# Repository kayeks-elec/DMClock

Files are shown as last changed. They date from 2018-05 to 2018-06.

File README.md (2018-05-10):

# DMCLOCK

## Overview

A Desktop clock project using AVR8 microcontroller and 32-by-16 dots LED matrix
module.

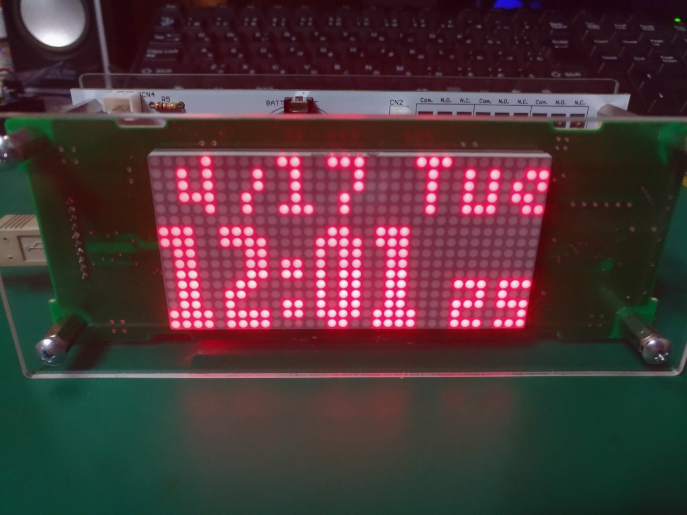
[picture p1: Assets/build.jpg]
Photo of a build


## Features
  - Display ambient temperature
  - Clock backup during power off
  - Four-level display brightness select, including automatic leveling with
    on-board ambient light sensor
  - Three-channel relay output triggerable by specified clock time and
    days-of-week.
  - Clock correction from GPS receiver
  - Serial message output (see below)

## Specifications
  - **Power**  
      - 5V DC from USB B connector, 250 mA typ., 800 mA max. including LED
        module
      - 3V DC from CR2032 cell, 10 nA typ. for clock backup
  - **Dimensions**  
    145 mm × 54 mm × 46 mm, viewing area 82 mm × 41 mm
  - **Devices**  
      - ATMEGA328P, clocked at 20 MHz
      - DS1307+ real-time clock
  - **Inputs**  
      - Two push switches
      - Ambient light sensor
      - Temperature sensor
      - GPS receiver module (optional)
  - **Outputs**  
      - Three relay channels with two throws each; max. load 2A 30V DC, 1A 125V
        AC
      - Serial message output: 5V level, 8N1 at 9600 baud
  - **Clock accuracy**  
    Less than 1 second of relative error from GPS clock source

## Targeting display device

The targeting LED matrix module in this project is Product Number of AD-501,
manufactured by *Alpha Device Co.* of Japan. It has a viewing area of
monochromatic 32-by-16 dots in matrix arrangement. Therefore, this project
would be portable to other devices which have similar viewing areas if you
replace the device-specific interfacing routines.

## Microcontroller

This project uses an ATMEGA328P microcontroller.

### Clock configuration

The clock is 20 MHz from crystal oscillator (ceramic resonator also works but not recommended).

### Flashing firmware

Flash firmware `Firmware/DotMatrixClock2018.hex` directly by ISP, with fuses
Low byte **0xFF**, High byte **0xD9**, and Extended byte **0x07**.

## GPS clock correction

External GPS modules can be connected to GPS Receiver connector (CN3) for clock
time correction.

The pin assignment for GPS Receiver connector (CN3):

| Pin # | Description |
| --: | :-- |
| 1 | +5V power supply, fused by 100 mA polyfuse |
| 2 | GND |
| 3 | not connected |
| 4 | GPS receiver source |
| 5 | GPS receiver sink |

Note:  
The data line through pins 4 and 5 constitutes a current loop driver, and
its driving current is 5 mA, which is similar to the conventional MIDI
interfaces.

Any GPS module which meets requirements below woule be available for this
project:
  - **Serial format**  
    8N1 at 9,600 baud
  - **Messages**  
    NMEA 0183 messages contain `$GPGGA` and `$GPZDA` sentences

## Serial message output

Messages are transmitted from Serial Output connector (CN4). The output level
is 5 V. Serial format is 8N1 at 9,600 baud.

### Message strings

#### Local clock date
```text
D([0-9][0-9])-([01][0-9])-([0-3][0-9])\r\n
  where \1: last two digits of years
        \2: months
        \3: days
```

#### Local clock time
```text
T([0-9][0-9]):([01][0-9]):([0-3][0-9])\r\n
  where \1: hours
        \2: minutes
        \3: seconds
```

#### Ambient temperature
```text
A([+-])([01][0-9][0-9].[0-9][0-9])\r\n
  if temperature is available
  where \1: sign of temperature
        \2: absolute value of temperature
A xxx.xx\r\n
  if temperature is unavailable
```

## License

Modified BSD License  
See `LICENSE` for details.

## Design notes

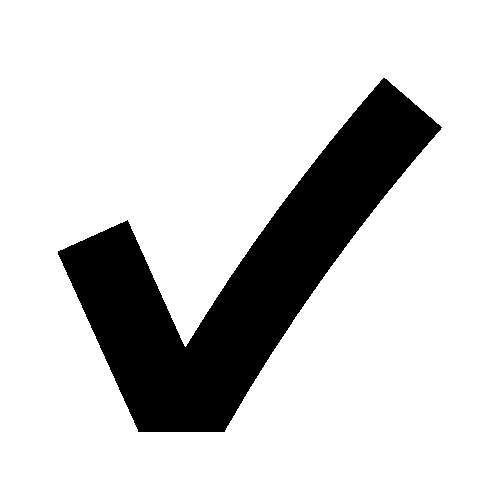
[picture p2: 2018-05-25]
Hardware/Mainboard/BallotSign.bmp

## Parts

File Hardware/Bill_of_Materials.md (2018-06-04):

# Bill of Materials

## Mainboard

| Nr. | Location | Category | Details | Qty. |
|----:|:---|:---|:---|-----:|
| 1 | R4 | carbon film resistor | 220 ohm | 1 |
| 2 | R1, R3, R5, R7, R9, R11 | carbon film resistor | 1K ohm | 6 |
| 3 | R12 | carbon film resistor | 2.2K ohm (depending on characteristics of RP) | 1 |
| 4 | R6, R8, R10 | carbon film resistor | 4.7K ohm | 3 |
| 5 | R2, R13, R14 | carbon film resistor | 10K ohm | 3 |
| 6 | RP | photocell | 10K - 20K ohm @ 10 lux, 1M ohm @ dark | 1 |
| 7 | F1 | resettable fuse | ≥10 V, 1.1 A | 1 |
| 8 | F2 | resettable fuse | ≥10 V, 0.1 A | 1 |
| 9 | C7, C8 | ceramic capacitor | 10 pF (depending on characteristics of Y2) | 2 |
| 10 | C4, C5 | ceramic capacitor | 22 pF (depending on characteristics of Y1) | 2 |
| 11 | C2, C3, C6, C9 | multilayer ceramic capacitor | 100 nF | 4 |
| 12 | C1 | electrolytic capacitor | ≥10 V, 220 uF | 1 |
| 13 | Y1 | crystal oscillator | 20.000 MHz | 1 |
| 14 | Y2 | crystal oscillator | 32.768 KHz | 1 |
| 15 | D1, D2, D3, D4 | rectifier diode | *1N4148* | 4 |
| 16 | LD1 | light emitting diode | *red* | 1 |
| 17 | LD2 | light emitting diode | *yellow green* | 1 |
| 18 | LD3, LD4, LD5 | light emitting diode | *yellow* | 3 |
| 19 | Q1, Q2, Q4, Q5, Q6 | NPN transistor | *2N3904* | 5 |
| 20 | Q3 | optoisolator | *PC817* | 1 |
| 21 | U1 | AVR8 microcontroller | ATMEGA328P-PU, `Firmware/DotMatrixClock2018.hex` programmed, fuses H=0xFF L=0xD9 E=0x07 | 1 |
| 22 | U2 | real-time clock | DS1307+ | 1 |
| 23 | U3 | digital temperature sensor | ADT7410TRZ | 1 |
| 24 | CN1 | USB B connector | | 1 |
| 25 | CN2 | JST PH connector | B10B-PH-K-S | 1 |
| 26 | CN3 | DIN connector | 5 poles | 1 |
| 27 | CN4 | pin header | 6 poles, single row, right angle | 1 |
| 28 | CN5, CN6, CN7 | solderless terminal block | 3 poles | 3 |
| 29 | CN8 | box header | 6 poles | 1 |
| 30 | BATT | CR2032 coin cell holder | | 1 |
| 31 | SW1, SW2 | push switch | | 2 |
| 32 | RY1, RY2, RY3 | magnetic relay | 5 V, double throw, *946H-1C-5D* | 3 |
| 33 | - | LED panel module | AD-501 from Alpha Device Co. | 1 |

## GPS Receiver

| Nr. | Location | Category | Details | Qty. |
|----:|:---|:---|:---|-----:|
| 1 | R1, R2 | carbon film resistor | 220 ohm | 2 |
| 2 | R3, R4 | carbon film resistor | 1K ohm | 2 |
| 3 | C1 | electrolytic capacitor | ≥10 V, 22 uF | 1 |
| 4 | U1 | GPS module | AE-GYSFDMAX from Akizuki Denshi | 2 |
| 5 | (U1) | pin header | 5 poles, single row | 1 |
| 6 | (U1) | pin socket | 5 poles, single row | 1 |
| 7 | (U1) | standoff | M3, 11mm, brass | 4 |
| 8 | (U1) | screw | M3, 5mm (+), steel | 8 |
| 9 | CN1 | DIN connector | 5 poles | 1 |
| 10 | CN2 | pin header | 6 poles, single row, right angle | 1 |
| 11 | CN3 | pin header | 2 poles, single row, right angle | 1 |

  - P/Ns described in italic are reference designs. You can replace them to
    compatible parts as your availability.

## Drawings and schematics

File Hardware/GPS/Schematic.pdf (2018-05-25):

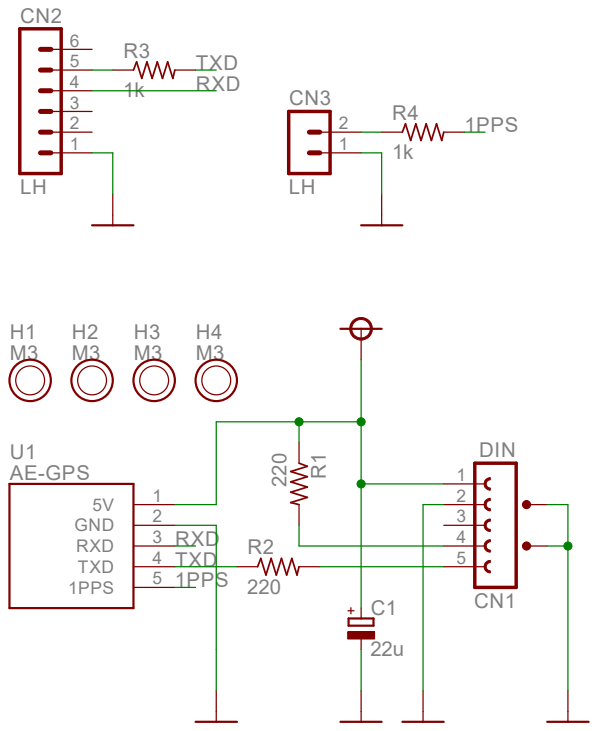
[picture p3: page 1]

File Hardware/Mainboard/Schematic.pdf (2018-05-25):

SCR.TERM. ¹k | 1N⁴¹⁴⁸ | 2.2k 10k | 10k | 10..20k@¹⁰lx/1M ⁰.1u | 0.1u 32.768k

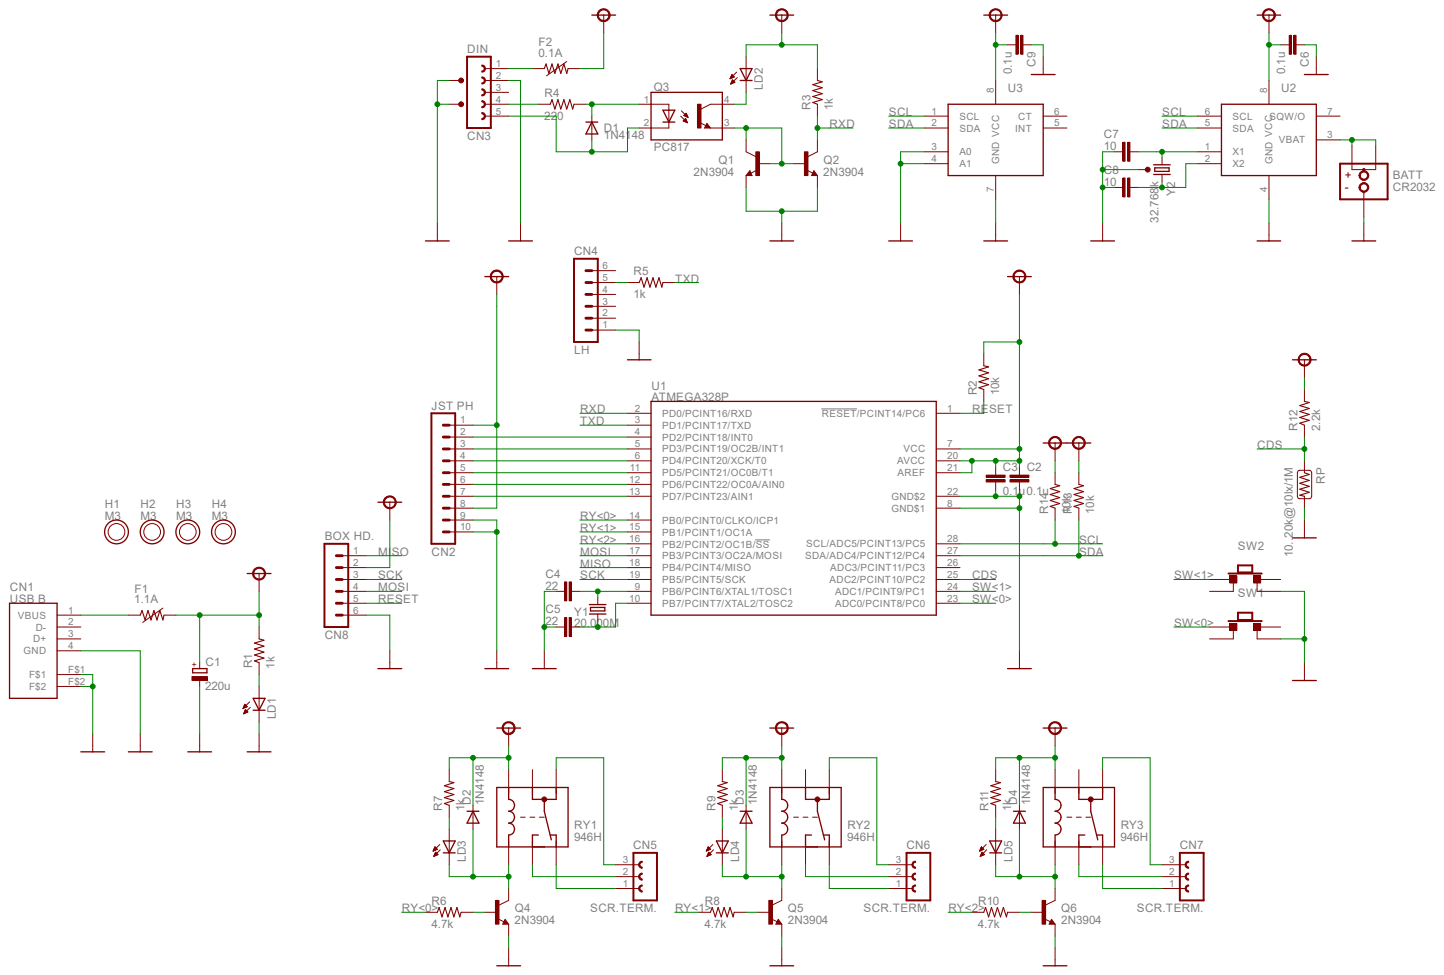
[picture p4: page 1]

PD5/PCINT21/OC0B/T1 11
PD6/PCINT22/OC0A/AIN0 12
PD7/PCINT23/AIN1 13

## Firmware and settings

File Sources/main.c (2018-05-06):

/*
 * DotMatrixClock2018/main.c
 *
 *  Author: kayekss
 *  Target: ATmega328P, 20.000 MHz crystal oscillator
 */

// System clock frequency in Hz
#define F_CPU  20000000ul

#include <stdint.h>
#include <stdbool.h>
#include <stdlib.h>
#include <string.h>
#include <avr/io.h>
#include <avr/interrupt.h>
#include "ctime.h"
#include "event.h"
#include "eeprom.h"
#include "eeprom_redundancy.h"
#include "keys.h"
#include "display.h"
#include "drawings.h"
#include "usart.h"
#include "nmea.h"
#include "twi.h"
#include "temp_adt7410.h"
#include "rtc_ds1307.h"
#include "adc.h"
#include "light_sensor.h"
#include "defs.h"

// -------- Global variables --------

// Elapsed time from startup in milliseconds
volatile uint32_t ticks = 0;

// Front frame buffer
extern uint32_t fb_front[16];

// ADC value of light sensor
uint16_t light_adc;

// USART receiver buffer
ringbuf_t rx;

// USART transmitter buffer
ringbuf_t tx;

// Working environment
struct {
    // Current status
    state_t status;
    // Current display brightness (0..4)
    uint8_t brightness;
    // Current internal time structure
    ctime_t ct;
    // Duplicated time structure used during modification
    ctime_t ct_mod;
    // Current week-of-day
    dow_t dow;
    // Week-of-day used during modification
    dow_t dow_mod;
    // GPS connection/tracking status
    struct {
        // Fix status
        gpstate_t status;
        // Satellites in use
        uint8_t sats_in_use;
    } gps;
    // T5 tasks
    struct {
        task5_t read_keys;
        task5_t read_temperature;
        task5_t draw_screen;
        task5_t get_light_level;
    } task5;
    // T6 tasks
    struct {
        task6_t save_ctime_to_rtc;
        task6_t check_relay_output;
        task6_t serial_output;
    } task6;
    // Key watchers
    key_t key0, key1;
    // Configuration structure and its duplication
    config_t config, config_mod;
    // Indexes used during relay setup in configuration mode
    struct {
        // Relay number currently indexing
        uint8_t r;
        // Event number currently indexing
        uint8_t e;
        // Day-of-week currently indexing
        dow_t dow;
    } relay_index;
    // Whether to save the configuration to EEPROM when it is done
    bool save_to_ee;
    // Buffer for EEPROM byte array
    uint8_t ee_blob[EEREDUN_CONFIG_STRIDE];
    // Temperature sensor status
    struct {
        // Result (0: no error, 1: error)
        bool result;
        // Temperature value
        temp_adt7410_t value;
        // Trigger flags
        uint8_t flags;
    } temperature;
    // Message buffer
    linebuf_t msg;
    // Ticks of last reception of '$' from USART
    uint32_t ticks_rx;
} env;

// Default clock time recalled on failure
ctime_t const ct_default = {
    1, 0, 1, 1, 0, 0, 0, 0
};

// EEPROM address map for configuration
eeredun_t const eer_config = {
    EEREDUN_CONFIG_REDUNDANCY,
    EEREDUN_CONFIG_STRIDE,
    { EEREDUN_CONFIG_BASE_TIMESTAMP, EEREDUN_CONFIG_BASE_ENTITY }
};

// -------- General functions --------

// Make an imprecise wait by busy-looping
void wait(uint32_t delay_ms) {
    uint32_t ticks_end_loop = ticks + delay_ms;

    while (ticks < ticks_end_loop);
}

// Get constrained value in range between specified
// ... minimum and maximum
inline uint8_t constrain(uint8_t n, uint8_t min, uint8_t max) {
    return n < min ? n : n > max ? max : n;
}

// Initialize T5 task
inline void t5_initialize(task5_t* t, uint32_t interval) {
    t->interval = interval;
    t->timestamp = 0;
}

// Check if the T5 task is triggered
inline bool t5_check_triggered(task5_t* t) {
    if (t->interval == 0) {
        return false;
    } else {
        return ticks >= t->timestamp + t->interval;
    }
}

// Set last-executed timestamp of the T5 task
inline void t5_set_timestamp(task5_t* t) {
    t->timestamp = ticks;
}

// Initialize T6 task
inline void t6_initialize(task6_t* t) {
    t->pending = false;
}

// Trigger T6 task
inline void t6_trigger(task6_t* t) {
    t->pending = true;
}

// Check if the T6 task is triggered
inline bool t6_check_triggered(task6_t* t) {
    return t->pending;
}

// Untrigger T6 task
inline void t6_done(task6_t* t) {
    t->pending = false;
}

// -------- Project-specific functions --------

// Setup EEPROM
void setup_eeprom() {
    EECR = (0 << EERIE) | (0 << EEMPE) | (0 << EEPE) | (0 << EERE);
    //     0b--XX0XXX  (-: reserved bits)
    //         |||||+-- EERE      EEPROM Read Enable
    //         ||||+--- EEPE      EEPROM Write Enable
    //         |||+---- EEMPE     EEPROM Master Write Enable 
    //         ||+----- EERIE     EEPROM Ready Interrupt Enable: no
    //         ++------ EEPM<1:0> EEPROM Programming Mode
}

// Setup I/O ports
void setup_io() {
    // == PORTB ==
    // PB7/XTAL2: crystal oscillator
    // PB6/XTAL1: crystal oscillator
    // PB5/SCK:   not in use, only for programming
    // PB4/MISO:  not in use, only for programming
    // PB3/MOSI:  not in use, only for programming
    // PB2:       Relay 2, normal-low output
    // PB1:       Relay 1, normal-low output
    // PB0:       Relay 0, normal-low output
    // == PORTC ==
    // PC6/RESET#: reset
    // PC5/SCL:    TWI serial bus clock
    // PC4/SDA:    TWI serial bus data
    // PC3:        not in use
    // PC2/ADC2:   Light sensor (photoresistor), analog input
    // PC1:        Push key 1, pulled-up input
    // PC0:        Push key 0, pulled-up input
    // == PORTD ==
    // PD7:     LED matrix module OE, output
    // PD6:     LED matrix module LAT, output
    // PD5:     LED matrix module CLK, output
    // PD4:     LED matrix module SIN3, output
    // PD3:     LED matrix module SIN2, output
    // PD2:     LED matrix module SIN1, output
    // PD1/TXD: USART transmitter, output
    // PD0/RXD: USART receiver, input
    PORTB = (0 << PORTB7) | (0 << PORTB6) | (0 << PORTB5) | (0 << PORTB4) |
        (0 << PORTB3) | (0 << PORTB2) | (0 << PORTB1) | (0 << PORTB0);
    //     0b00000000
    //       ++++++++-- PORTB<7:0> Port B Data
    DDRB = (0 << DDB7) | (0 << DDB6) | (0 << DDB5) | (0 << DDB4) |
        (0 << DDB3) | (1 << DDB2) | (1 << DDB1) | (1 << DDB0);
    //     0b00000111
    //       ++++++++-- DDRB<7:0> Port B Data Direction
    PORTC = (0 << PORTC6) | (0 << PORTC5) | (0 << PORTC4) |
        (0 << PORTC3) | (0 << PORTC2) | (1 << PORTC1) | (1 << PORTC0);
    //     0b-0000011  (-: reserved bits)
    //        +++++++-- PORTC<6:0> Port C Data
    DDRC = (0 << DDC6) | (0 << DDC5) | (0 << DDC4) |
        (0 << DDC3) | (0 << DDC2) | (0 << DDC1) | (0 << DDC0);
    //     0b-0000000  (-: reserved bits)
    //        +++++++-- DDRC<6:0> Port C Data Direction
    PORTD = (0 << PORTD7) | (0 << PORTD6) | (0 << PORTD5) | (0 << PORTD4) |
        (0 << PORTD3) | (0 << PORTD2) | (0 << PORTD1) | (0 << PORTD0);
    //     0b00000000
    //       ++++++++-- PORTD<7:0> Port D Data
    DDRD = (1 << DDD7) | (1 << DDD6) | (1 << DDD5) | (1 << DDD4) |
        (1 << DDD3) | (1 << DDD2) | (1 << DDD1) | (0 << DDD0);
    //     0b11111110
    //       ++++++++-- DDRD<7:0> Port D Data Direction
}

// Setup Timer/Counter 0
void setup_timer0() {
    TCCR0A = (0 << COM0A1) | (0 << COM0A0) | (0 << COM0B1) | (0 << COM0B0) |
        (1 << WGM01) | (0 << WGM00);
    //     0b0000--10  (-: reserved bits)
    //       ||||  ++-- WGM0<1:0>  Waveform Generation: CTC, TOP=OCR0A
    //       ||++------ COM0B<1:0> Compare Output Mode B: Normal
    //       ++-------- COM0A<1:0> Compare Output Mode A: Normal
    TCCR0B = (0 << FOC0A) | (0 << FOC0B) | (0 << WGM02) |
        (0 << CS02) | (1 << CS01) | (1 << CS00);
    //     0b00--0011  (-: reserved bits)
    //       ||  |+++-- CS0<2:0> Clock Select: clkI/O / 64
    //       ||  +----- WGM02    Waveform Generation  *see TCCR0A
    //       |+-------- FOC0B    Force Output Compare B  *unused
    //       +--------- FOC0A    Force Output Compare A  *unused
        TIMSK0 = (0 << OCIE0B) | (1 << OCIE0A) | (0 << TOIE0);
    //     0b-----010  (-: reserved bits)
    //            ||+-- TOIE0   Overflow Interrupt Enable: no
    //            |+--- OCIE0A  Compare A Match Int. Enable: yes
    //            +---- OCIE0B  Compare B Match Int. Enable: no

    // 20e+6[Hz(CPU)] / 4000[Hz(int)] / 64[prescaler]
    // ... actual value is 78.125, error rate +0.16%
    OCR0A = F_CPU / 4000 / 64 - 1;
    OCR0B = 0;

    // Clear counter
    TCNT0 = 0;
}

// Setup Timer/Counter 1
void setup_timer1() {
    TCCR1A = (0 << COM1A1) | (0 << COM1A0) | (0 << COM1B1) | (0 << COM1B0) |
        (0 << WGM11) | (0 << WGM10);
    //     0b0000--00  (-: reserved bits)
    //       ||||  ++-- WGM1<1:0>  Waveform Generation: CTC, TOP=OCR1A
    //       ||++------ COM1B<1:0> Compare Output Mode B: Normal
    //       ++-------- COM1A<1:0> Compare Output Mode A: Normal
    TCCR1B = (0 << ICNC1) | (0 << ICES1) | (0 << WGM13) | (1 << WGM12) |
        (0 << CS12) | (0 << CS11) | (1 << CS10);
    //     0b00-01001  (-: reserved bits)
    //       || ||+++-- CS1<2:0>  Clock Select: clkI/O / 1
    //       || ++----- WGM1<3:2> Waveform Generation  *see TCCR1A
    //       |+-------- ICES1     Input Capture Edge Select  *unused
    //       +--------- ICNC1     Input Capture Noise Canceler  *unused
    TCCR1C = (0 << FOC1A) | (0 << FOC1B);
    //     0b00------  (-: reserved bits)
    //       |+-------- FOC1B  Force Output Compare B  *unused
    //       +--------- FOC1A  Force Output Compare A  *unused
    TIMSK1 = (0 << ICIE1) | (0 << OCIE1B) | (1 << OCIE1A) | (0 << TOIE1);
    //     0b--0--010  (-: reserved bits)
    //         |  ||+-- TOIE1   Overflow Interrupt Enable: No
    //         |  |+--- OCIE1A  Compare A Match Interrupt Enable: yes
    //         |  +---- OCIE1B  Compare B Match Interrupt Enable: no
    //         +------- ICIE1   Input Capture Interrupt Enable: no

    // 20e+6[Hz(CPU)] / 1000[Hz(int)] / 1[prescaler]
    // ... actual value is 20000, error rate 0.00%
    OCR1A = F_CPU / 1000 / 1 - 1;
    OCR1B = 0;

    // Clear counter
    TCNT1 = 0;
}

// Setup USART 0
void setup_usart0() {
    UCSR0A = (0 << TXC0) | (0 << U2X0) | (0 << MPCM0);
    //     0bR0RRRR00  (R: read-only bits)
    //       |||||||+-- MPCM0  Multi-processor Communication Mode  *unused
    //       ||||||+--- U2X0   Double the USART Transmission Speed: no
    //       |||||+---- UPE0   USART Parity Error
    //       ||||+----- DOR0   Data Overrun
    //       |||+------ FE0    Frame Error
    //       ||+------- UDRE0  USART Data Register Empty
    //       |+-------- TXC0   USART Transmit Complete
    //       +--------- RXC0   USART Receive Complete
    UCSR0B = (1 << RXCIE0) | (0 << TXCIE0) | (0 << UDRIE0) | (1 << RXEN0) |
        (1 << TXEN0) | (0 << UCSZ02) | (0 << TXB80);
    //     0b10X110R0  (R: read-only bits)
    //       |||||||+-- TXB80   Transmit Data Bit 8
    //       ||||||+--- RXB80   Receive Data Bit 8
    //       |||||+---- UCSZ02  Character Size  *see UCSR0C
    //       ||||+----- TXEN0   Transmitter Enable: yes
    //       |||+------ RXEN0   Receiver Enable: yes
    //       ||+------- UDRIE0  Data Register Empty Interrupt Enable
    //       |+-------- TXCIE0  TX Complete Interrupt Enable: no
    //       +--------- RXCIE0  RX Complete Interrupt Enable: yes
    UCSR0C = (0 << UMSEL01) | (0 << UMSEL00) | (0 << UPM01) | (0 << UPM00) |
        (0 << USBS0) | (1 << UCSZ01) | (1 << UCSZ00) | (0 << UCPOL0);
    //     0b00000110
    //       |||||||+-- UCPOL0      Clock Polarity  *unused
    //       |||||++--- UCSZ0<1:0>  Character Size: 8-bit
    //       ||||+----- USBS0       USART Stop Bit Select: 1-bit
    //       ||++------ UPM0<1:0>   USART Parity Mode: Disabled
    //       ++-------- UMSEL0<1:0> USART Mode Select: Asynchronous USART

    // 20e+6[Hz(CPU)] / 9600[baud] / 16 * 1[doubler]
    // ... actual value is 130.21, error rate +0.16%
    UBRR0 = F_CPU / 9600 / 16 * 1 - 1;
}

// Setup Two-wire Serial Interface
void setup_twi() {
    TWCR = (0 << TWINT) | (0 << TWEA) | (0 << TWSTA) | (0 << TWSTO) |
        (1 << TWEN) | (0 << TWIE);
    //     0b00XXR1-0  (-: reserved bits, R: read-only bits)
    //       |||||| +-- TWIE   TWI Interrupt Enable: no
    //       |||||+---- TWEN   TWI Enable: yes
    //       ||||+----- TWWC   TWI Write Collision Flag
    //       |||+------ TWSTO  TWI Stop Condition
    //       ||+------- TWSTA  TWI Start Condition
    //       |+-------- TWEA   TWI Enable Acknowledge: no
    //       +--------- TWINT  TWI Interrupt Flag
    TWSR = (0 << TWPS1) | (0 << TWPS0);
    //     0bRRRRR-00  (-: reserved bits, R: read-only bits)
    //       ||||| ++-- TWPS<1:0> TWI Prescaler: 1
    //       +++++----- TWS<7:3>  TWI Status Bit
    TWDR = 0x00;

    // (20e+6[Hz(CPU)] / 100e+3[Hz(SCL)] - 16) / 1[prescaler] / 2
    // ... actual value is 92, error rate 0.00%
    TWBR = (F_CPU / 100000 - 16) / 1 / 2;
}

// Setup Analog to Digital Converter
void setup_adc() {
    ADMUX = (0 << REFS1) | (0 << REFS0) | (0 << ADLAR);
    //     0b000-XXXX  (-: reserved bits)
    //       ||| ++++-- MUX<3:0>  Analog Channel Selection
    //       ||+------- ADLAR     ADC Left Adjust: no
    //       ++-------- REFS<1:0> Reference Selection: AREF
    ADCSRA = (1 << ADEN) | (0 << ADATE) | (0 << ADIE) | (0 << ADIF) |
        (1 << ADPS2) | (1 << ADPS1) | (1 << ADPS0);
    //     0b1X0X0111
    //       |||||+++-- ADPS<2:0> ADC Prescaler Select: 128
    //       ||||+----- ADIE      ADC Interrupt Enable: no
    //       |||+------ ADIF      ADC Interrupt Flag
    //       ||+------- ADATE     ADC Auto Trigger Enable: no
    //       |+-------- ADSC      ADC Start Conversion
    //       +--------- ADEN      ADC Enable: yes
    ADCSRB = (ADCSRB & 0x40) | (0 << ADTS2) | (0 << ADTS1) | (0 << ADTS0);
    //     0b-?---000  (-: reserved bits, ?: bits used in other functions)
    //        |   +++-- ADTS<2:0> ADC Auto Trigger Source  *unused
    //        +-------- ACME      Analog Comparator Multiplexer Enable
    DIDR0  = (0 << ADC5D) | (0 << ADC4D) | (0 << ADC3D) | (1 << ADC2D) |
        (0 << ADC1D) | (0 << ADC0D);
    //     0b--000100  (-: reserved bits)
    //         ++++++-- ADC<5:0>D  ADC Digital Input Disable
}

// Timer/Counter 0 Compare Match A interrupt vector
ISR(TIMER0_COMPA_vect) {
    // Line to display for this time (0..15)
    static uint8_t y = 0;
    // PWM phase (0..3)
    static uint8_t pwm = 0;
    // Frame buffer line to send to the display for this time
    uint32_t fbline;
    
    // Get target line from frame buffer
    fbline = pwm < env.brightness ? fb_front[y] : 0x0000000ul;

    // Set latch to low
    PORTD &= ~(1 << PORTD6);
    // Send buffer line as 16-bit serial data
    for (uint8_t i = 0; i < 16; i++) {
        // Set clock to low
        PORTD &= ~(1 << PORTD5);
        // Set data;
        //   PD2: line driver
        //   PD3: column driver for left half
        //   PD4: column driver for right half
        PORTD = (PORTD & 0xe3) |
            (i == y ? (1 << PORTD2) : 0x00) |
            ((fbline & (0x00010000ul << i)) ? (1 << PORTD3) : 0x00) |
            ((fbline & (0x00000001ul << i)) ? (1 << PORTD4) : 0x00);
        // Set clock to high; data is read by the display
        PORTD |= (1 << PORTD5);
    }
    // Set latch to low; display is updated
    PORTD |= (1 << PORTD6);

    // Advance line
    if (y == 15) {
        y = 0;
        // Advance PWM phase
        pwm = (pwm + 1) & 0x03;
    } else {
        y++;
    }
}

// Timer/Counter 0 Compare Match A interrupt vector
ISR(TIMER1_COMPA_vect) {
    uint8_t carry;
    
    // Increment ticks
    ticks++;
    // Increment clock ticks
    carry = ctime_increment_tick(&env.ct);
    if (carry & (1 << 0)) {
        // Validate clock time on every second
        ctime_check_error(&env.ct);
    }
    if (carry & (1 << 1)) {
        // Recalculate week-of-day on every minute
        env.dow = dayofweek(&env.ct);
        // Trigger tasks as clock time advances
        t6_trigger(&env.task6.save_ctime_to_rtc);
        t6_trigger(&env.task6.check_relay_output);
        t6_trigger(&env.task6.serial_output);
    }
    // Check if GPS connection is timed out
    if (ticks >= env.ticks_rx + GPS_CONNECTION_LOST_TIMEOUT_MS) {
        env.gps.status = GP_ABSENT;
        env.gps.sats_in_use = 0;
    }
}

// USART Receive Complete interrupt vector
ISR(USART_RX_vect) {
    uint8_t c = UDR0;
    uint32_t ticks0 = ticks;
    
    ringbuf_put(&rx, c);
    if (c == '$') {
        env.ticks_rx = ticks0;
    }
}

// USART Data Register Empty interrupt vector
ISR(USART_UDRE_vect) {
    uint8_t c = 0;

    if (ringbuf_available(&tx)) {
        ringbuf_get(&tx, &c);
        usart_putc(c);
    } else {
        // Disable further interrupts
        UCSR0B &= ~(1 << UDRIE0);
    }
}

// Setup configuration structure to fallback value 
void setup_fallback_config(config_t* config) {
    config->state_startup = ST_NORMAL_TIME_HM | ST_NORMAL_DATE_WEEKOFDAY;
    config->use_gps = false;
    for (uint8_t j = 0; j < 3; j++) {
        config->relay[j].count = 0;
        for (uint8_t i = 0; i < NUM_EVENT_ENTRIES_PER_ITEM; i++) {
            event_clear(&config->relay[j].ev[i]);
        }
    }
    config->brightness = 2;
}

// Import configuration structure from EEPROM byte array
void import_config_from_blob(config_t* config, uint8_t* blob) {
    uint8_t const stride_j = 5 * NUM_EVENT_ENTRIES_PER_ITEM + 1;
    uint8_t const stride_i = 5;
    event_t ev_temp = { { 0, 0 }, { 0, 0 }, ~0 };

    // Load default value when invalid startup state is read
    if (blob[0] & ST_MASK) {
        config->state_startup = ST_NORMAL_TIME_HMS | ST_NORMAL_DATE_WEEKOFDAY;
    } else {
        config->state_startup = blob[0] & ~ST_MASK;
    }
    config->use_gps = !!blob[1];
    for (uint8_t j = 0; j < 3; j++) {
        // Void all events when event count is out-of-range
        if (blob[2 + stride_j * j] > NUM_EVENT_ENTRIES_PER_ITEM) {
            config->relay[j].count = 0;
        } else {
            config->relay[j].count = blob[2 + stride_j * j];
        }
        for (uint8_t i = 0; i < config->relay[j].count; i++) {
            ev_temp.on.h = blob[2 + stride_j * j + stride_i * i + 1];
            ev_temp.on.m = blob[2 + stride_j * j + stride_i * i + 2];
            ev_temp.off.h = blob[2 + stride_j * j + stride_i * i + 3];
            ev_temp.off.m = blob[2 + stride_j * j + stride_i * i + 4];
            ev_temp.mask = blob[2 + stride_j * j + stride_i * i + 5] | 0x01;
            event_fix_problems(&ev_temp);
            config->relay[j].ev[i] = ev_temp;
        }
        event_clear(&ev_temp);
        for (uint8_t i = config->relay[j].count;
            i < NUM_EVENT_ENTRIES_PER_ITEM; i++) {
            config->relay[j].ev[i] = ev_temp;
        }
    }
    config->brightness = constrain(blob[2 + stride_j * 3], 1, 5);
}
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
int main(void) {
    // -------- Setup --------
    
    // Initialize timing variables
    ticks = 0;
    env.ticks_rx = 0;

    // Initialize tasks
    t5_initialize(&env.task5.read_keys, T5_READ_KEYS_INTERVAL_MS);
    t5_initialize(&env.task5.read_temperature, T5_READ_TEMPERATURE_INTERVAL_MS);
    t5_initialize(&env.task5.draw_screen, T5_DRAW_SCREEN_INTERVAL_MS);
    t5_initialize(&env.task5.get_light_level, T5_GET_LIGHT_LEVEL_INTERVAL_MS);
    t6_initialize(&env.task6.save_ctime_to_rtc);
    t6_initialize(&env.task6.check_relay_output);
    t6_initialize(&env.task6.serial_output);

    // Initialize key watchers
    key_initialize(&env.key0);
    key_initialize(&env.key1);
    
    // Setup USART buffers
    ringbuf_initialize(&rx, RX_BUFFER_LENGTH);
    ringbuf_initialize(&tx, TX_BUFFER_LENGTH);
    linebuf_initialize(&env.msg, MESSAGE_BUFFER_LENGTH);

    // Initialize GPS status
    env.gps.status = GP_ABSENT;
    env.gps.sats_in_use = 0;
    
    // Setup SFRs
    setup_eeprom();
    setup_io();
    setup_timer0();
    setup_timer1();
    setup_usart0();
    setup_twi();
    setup_adc();

    // Enable all interrupts
    sei();
    
    // Restore configurations from EEPROM
    eeprom_redun_read((eeredun_t*) &eer_config, env.ee_blob);
    import_config_from_blob(&env.config, env.ee_blob);
    env.status = env.config.state_startup;

    // Setup temperature sensor
    env.temperature.result = 1;
    env.temperature.value.sign = 0;
    env.temperature.value.integer = 0;
    env.temperature.value.fraction_x10k = 0;
    env.temperature.flags = 0x00;
    temp_adt7410_set_config(
        CONFIG_ADT7410_FAULT_1 | CONFIG_ADT7410_POL_INTL_CTL |
        CONFIG_ADT7410_INTMODE_INT | CONFIG_ADT7410_OPMODE_CONT |
        CONFIG_ADT7410_RESOL_13BITS);
    // Read RTC on startup
    ctime_t ct_r;
    dow_t dow_r;
    bool success = false;
    for (uint8_t i = 0; i < RETRY_COUNT_READ_RTC_ON_STARTUP && !success; i++) {
        rtc_ds1307_read_clock(&ct_r, &dow_r);
        if (ctime_check_error(&ct_r) == 0x00) {
            // If any valid time has been read, set it to clock time
            env.ct = ct_r;
            env.dow = dayofweek((ctime_t*) &env.ct);
            success = true;
        }
        wait(2);
    }
    if (!success) {
        // On multiple attempts fail, load the default clock time
        env.ct = ct_default;
        env.dow = dayofweek((ctime_t*) &ct_default);
    }
    // Trigger relay output
    t6_trigger(&env.task6.check_relay_output);

    // -------- Loop --------

    while (true) {
        task5_read_keys();
        task5_read_temperature();
        task5_draw_screen();
        task5_set_brightness();
        task6_save_ctime_to_rtc();
        task6_check_relay_output();
        task6_serial_output();
        task9_handle_rx();
    }
}

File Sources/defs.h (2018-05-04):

/*
 * DotMatrixClock2018/defs.h
 *
 *  Author: kayekss
 *  Target: ATmega328P, 20.000 MHz crystal oscillator
 */

#ifndef DEFS_DOTMATRIXCLOCK2018_H_
#define DEFS_DOTMATRIXCLOCK2018_H_

// USART receiver buffer length
#define RX_BUFFER_LENGTH                   32
// USART transmitter buffer length
#define TX_BUFFER_LENGTH                   32

// GPS NMEA message buffer length
#define MESSAGE_BUFFER_LENGTH             192

// EEPROM address map
#define EEREDUN_CONFIG_REDUNDANCY           7
#define EEREDUN_CONFIG_STRIDE             128
#define EEREDUN_CONFIG_BASE_TIMESTAMP  0x0010
#define EEREDUN_CONFIG_BASE_ENTITY     0x0080

// Number of event entries per item
#define NUM_EVENT_ENTRIES_PER_ITEM          8

// Interval for T5 tasks in milliseconds
#define T5_READ_KEYS_INTERVAL_MS           20
#define T5_READ_TEMPERATURE_INTERVAL_MS   600
#define T5_DRAW_SCREEN_INTERVAL_MS         20
#define T5_GET_LIGHT_LEVEL_INTERVAL_MS    200

// Retry count for reading RTC on startup
#define RETRY_COUNT_READ_RTC_ON_STARTUP    10

// Receiver timeout to GPS connection loss
#define GPS_CONNECTION_LOST_TIMEOUT_MS   5000

// T5 task
typedef struct {
    // Trigger interval in ticks 
    uint32_t interval;
    // Timestamp of last execution in ticks
    uint32_t timestamp;
} task5_t;

// T6 task
typedef struct {
    // Pending flag
    bool pending;
} task6_t;

// Enumeration table for states
typedef enum {
    ST_NORMAL_TIME_HM                = 0x01,
    ST_NORMAL_TIME_HMS               = 0x02,
    ST_NORMAL_DATE_WEEKOFDAY         = 0x04,
    ST_NORMAL_DATE_YEARS             = 0x08,
    ST_NORMAL_TEMPERATURE            = 0x0c,
    ST_NORMAL_GPS_STATUS             = 0x10,
    ST_CONFIG_USE_GPS                = 0x20,
    ST_CONFIG_SET_TIME_TOP           = 0x21,
    ST_CONFIG_SET_TIME_MOD_YH        = 0x40,
    ST_CONFIG_SET_TIME_MOD_YL        = 0x41,
    ST_CONFIG_SET_TIME_MOD_MO        = 0x42,
    ST_CONFIG_SET_TIME_MOD_D         = 0x43,
    ST_CONFIG_SET_TIME_MOD_H         = 0x44,
    ST_CONFIG_SET_TIME_MOD_MH        = 0x45,
    ST_CONFIG_SET_TIME_MOD_ML        = 0x46,
    ST_CONFIG_SET_TIME_MOD_CONFIRM   = 0x47,
    ST_CONFIG_RELAY_EVENT_TOP        = 0x22,
    ST_CONFIG_RELAY_EVENT_MOD        = 0x60,
    ST_CONFIG_RELAY_EVENT_MOD_ON_H   = 0x61,
    ST_CONFIG_RELAY_EVENT_MOD_ON_MH  = 0x62,
    ST_CONFIG_RELAY_EVENT_MOD_ON_ML  = 0x63,
    ST_CONFIG_RELAY_EVENT_MOD_OFF_H  = 0x64,
    ST_CONFIG_RELAY_EVENT_MOD_OFF_MH = 0x65,
    ST_CONFIG_RELAY_EVENT_MOD_OFF_ML = 0x66,
    ST_CONFIG_RELAY_EVENT_MASK       = 0x23,
    ST_CONFIG_BRIGHTNESS             = 0x24,
    ST_CONFIG_SAVE_CONFIRM           = 0x25,
    ST_MISC_LIGHT_SENSOR             = 0xe0
} state_t;
// Branching bit masks
enum {
    ST_NORMAL_BITS                 = 0x00,
    ST_CONFIG_SET_TIME_MOD_BITS    = 0x40,
    ST_CONFIG_RELAY_EVENT_MOD_BITS = 0x60
};
enum {
    ST_MASK              = 0xe0,
    ST_NORMAL_LOWER_MASK = 0xe3,
    ST_NORMAL_UPPER_MASK = 0xfc
};

// Enumeration table of GPS states
typedef enum {
    GP_ABSENT   = 0xff,
    GP_NO_FIX   = 0x00,
    GP_GPS_FIX  = 0x01,
    GP_DGPS_FIX = 0x02
} gpstate_t;

// Configuration structure
typedef struct {
    // State on startup
    state_t state_startup;
    // Use GPS input for time adjustment
    bool use_gps;
    // Relay events
    struct {
        // Events registered
        uint8_t count;
        // Event entries
        event_t ev[NUM_EVENT_ENTRIES_PER_ITEM];
    } relay[3];
    // Display brightness (1..4: fixed, 5..: automatic)
    uint8_t brightness;
} config_t;

#endif

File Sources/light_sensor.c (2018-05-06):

/*
 * DotMatrixClock2018/light_sensor.c
 *
 *  Author: kayekss
 *  Target: ATmega328P, 20.000 MHz crystal oscillator
 */

#include <stdint.h>
#include "light_sensor.h"

// Get brightness level by ADC result, with hysteresis transition
uint8_t adc_to_brightness_level(uint16_t adc, uint8_t c_level) {
    uint8_t result = 0;
    uint16_t const lut_brightness_threshold[] = {
        BRIGHTNESS_THRESHOLD0,
        BRIGHTNESS_THRESHOLD1,
        BRIGHTNESS_THRESHOLD2,
        BRIGHTNESS_THRESHOLD3,
        BRIGHTNESS_THRESHOLD4
    };
    
    if (c_level != 0 && adc >= lut_brightness_threshold[c_level - 1]) {
        result = c_level - 1;
    } else if (c_level != 4 && adc <= lut_brightness_threshold[c_level + 1]) {
        result = c_level + 1;
    } else {
        result = c_level;
    }
    return result;
}

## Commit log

2018-05-06 Apply hysteresis brightness leveling, +2 changes
    1. Apply hysteresis brightness leveling to avoid flickering
    2. Fix problem on GPS message buffer occasionally stucked
    3. Prettify GPS status display, including fix quality from NMEA messages
    [display.c, drawings.c, light_sensor.c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]
2018-05-10 Fix mismatch of strings in void draw_config_relay_event_mask, +2 changes 1. Fix mismatch of strings in void draw_config_relay_event_mask 2. Fix newline code of nmea.c 3. Fix README.md
    [drawings.c]
2018-05-25 Revise PCB artwork
    [DMClock2018.GBL, DMClock2018.GBO, DMClock2018.GBP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]
2018-06-04 Add Bill of Materials
